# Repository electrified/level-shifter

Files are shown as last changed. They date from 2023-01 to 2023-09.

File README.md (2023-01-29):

## Board to interface 3.3v FPGA board with RC2014

## BOM

5x SN74CB3T3245

LD1117S33TR

100nF 0805 capacitors

10μF 0805 capacitors

## License

Copyright Ed Brindley 2020.

This source describes Open Hardware and is licensed under the CERN-OHL-P v2
You may redistribute and modify this documentation and make products using it under the terms of the CERN-OHL-P v2 (https:/cern.ch/cern-ohl). This documentation is distributed WITHOUT ANY EXPRESS OR IMPLIED WARRANTY, INCLUDING OF MERCHANTABILITY, SATISFACTORY QUALITY AND FITNESS FOR A PARTICULAR PURPOSE. Please see the CERN-OHL-P v2 for applicable conditions

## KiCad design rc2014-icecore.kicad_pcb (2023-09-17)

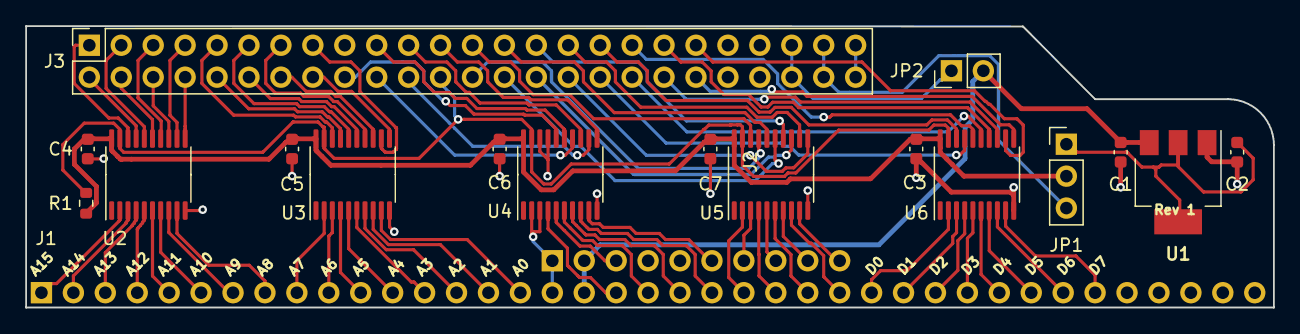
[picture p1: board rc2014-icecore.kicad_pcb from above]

Board: 2 copper layers, 99.3 x 22.4 mm, 19 parts (0 on the bottom side), 83 nets.

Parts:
C1: 100nF; C_0603_1608Metric
C2: 10uF; C_0603_1608Metric
C3, C4, C5, C6, C7: C; C_0603_1608Metric
J1: Conn_01x39; PinHeader_1x39_P2.54mm_Vertical_NoSilk
J2: Conn_01x10; PinHeader_1x10_P2.54mm_Vertical_NoSilk
J3: Conn_02x25_Odd_Even; PinSocket_2x25_P2.54mm_Vertical
JP1: Ext Power; PinHeader_1x03_P2.54mm_Vertical
JP2: Jumper; PinHeader_1x02_P2.54mm_Vertical
R1: R; R_0603_1608Metric
U1: LM1117-3.3; SOT-223-3_TabPin2
U2, U3, U4, U5, U6: SN74CB3T3245; TSSOP-20_4.4x6.5mm_P0.65mm

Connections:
+3V3: C3.1, C4.1, C5.1, C6.1, C7.1, JP1.2, R1.1, U2.20, U3.20, U4.20, U5.20, U6.20
+5V: C1.1, J1.18, J2.2, JP2.2, U1.3
//IORQ: J1.26, U5.8
//RD: J1.25, U5.6
//RESET: J1.20, U4.6
//WR: J1.24, U5.4
/A0: J1.16, U3.9
/A1: J1.15, U3.8
/A2: J1.14, U3.7
/A3: J1.13, U3.6
/A4: J1.12, U3.5
/A5: J1.11, U3.4
/A6: J1.10, U3.3
/A7: J1.9, U3.2
/A8: J1.8, U2.9
/A9: J1.7, U2.8
/A10: J1.6, U2.7
/A11: J1.5, U2.6
/A12: J1.4, U2.5
/A13: J1.3, U2.4
/A14: J1.2, U2.3
/A15: J1.1, U2.2
/BUSACK: J2.6, U4.9
/CLK: J1.21, U4.7
/D0: J1.27, U6.2
/D1: J1.28, U6.3
/D2: J1.29, U6.4
/D3: J1.30, U6.5
/D4: J1.31, U6.6
/D5: J1.32, U6.7
/D6: J1.33, U6.8
/D7: J1.34, U6.9
/FPGA_VCC: J3.47, J3.48, JP1.3
/INT: J1.22, U4.8
/M1: J1.19, U4.4
/MREQ: J1.23, U5.2
/P0: J3.1, U2.18
/P1: J3.2, U2.17
/P2: J3.3, U2.16
/P3: J3.4, U2.15
/P4: J3.5, U2.14
/P5: J3.6, U2.13
/P6: J3.7, U2.12
/P7: J3.8, U2.11
/P8: J3.9, U3.18
/P9: J3.10, U3.17
/P10: J3.11, U3.16
/P11: J3.12, U3.15
/P12: J3.13, U3.14
/P13: J3.14, U3.13
/P14: J3.15, U3.12
/P15: J3.16, U3.11
/P17: J3.18, U4.16
/P18: J3.19, U4.15
/P19: J3.20, U4.14
/P20: J3.21, U4.13
/P21: J3.22, U4.12
/P22: J3.23, U4.11
/P23: J3.24, R1.2, U2.19, U3.19, U4.19, U5.19, U6.19
/P24: J3.25, U5.18
/P25: J3.26, U5.17
/P26: J3.27, U5.16
/P27: J3.28, U5.15
/P28: J3.29, U5.14
/P29: J3.30, U5.13
/P30: J3.31, U5.12
/P31: J3.32, U5.11
/P48: J3.33, U6.18
/P49: J3.34, U6.17
/P50: J3.35, U6.16
/P51: J3.36, U6.15
/P52: J3.37, U6.14
/P53: J3.38, U6.13
/P54: J3.39, U6.12
/P55: J3.40, U6.11
/~BUSREQ: J2.8, U5.5
/~HALT: J2.7, U5.3
/~NMI: J2.10, U5.9
/~RFSH: J2.3, U4.5
/~WAIT: J2.9, U5.7
GND: C1.2, C2.2, C3.2, C4.2, C5.2, C6.2, C7.2, J1.17, J2.1, J3.49, J3.50, U1.1, U2.10, U3.10, U4.2, U4.3, U4.10, U4.17, U4.18, U5.10, U6.10
unnamed: C2.1, JP1.1, U1.2
unnamed: J3.45, J3.46, JP2.1

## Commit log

2020-10-20 WIP of level shifter
    [rc2014-icecore.dsn, rc2014-icecore.kicad_pcb, rc2014-icecore.sch]
2020-10-22 Rev 1 as sent to JLCPCB
    [rc2014-icecore-B_Cu.gbl, rc2014-icecore-B_Mask.gbs, rc2014-icecore-B_Paste.gbp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]
2023-01-29 Update for Kicad 6
    [rc2014-icecore.dsn, rc2014-icecore.kicad_pcb, rc2014-icecore.kicad_sch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]
2023-01-29 Further Kicad 6 updates
    [rc2014-icecore.kicad_sch]
2023-09-17 Update to kicad 7
    [rc2014-icecore.kicad_pcb, rc2014-icecore.kicad_sch]
